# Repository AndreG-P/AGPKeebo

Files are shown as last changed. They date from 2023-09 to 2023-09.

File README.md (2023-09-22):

# AGPKeebo

The AGPKeebo is a 78 keys keyboard with a couple of unique features:

* General 65% layout with one extra key (language switch) on Row 5 (right-ALT and right-CTRL are U1)
* F1 - F10 keys in two separated columns
* 2x customizable knobs with push button function
* Each key contains two independent LEDs (1 north-facing and 1 south-facing LED)
* Additional independent LEDs for underglow
* 1x USB 2.0 Type C output for additional peripherals
* 1x SD Card reader

The main purpose of the two independent north- and south-facing LEDs was to allow highlighting certain keys for different language settings (e.g. highlight German "umlaute" such as ü or ö as side prints on the keys). However, this feature would require novel keycaps which do not exist yet. Making such keycaps are beyond the limitations of this project for now.

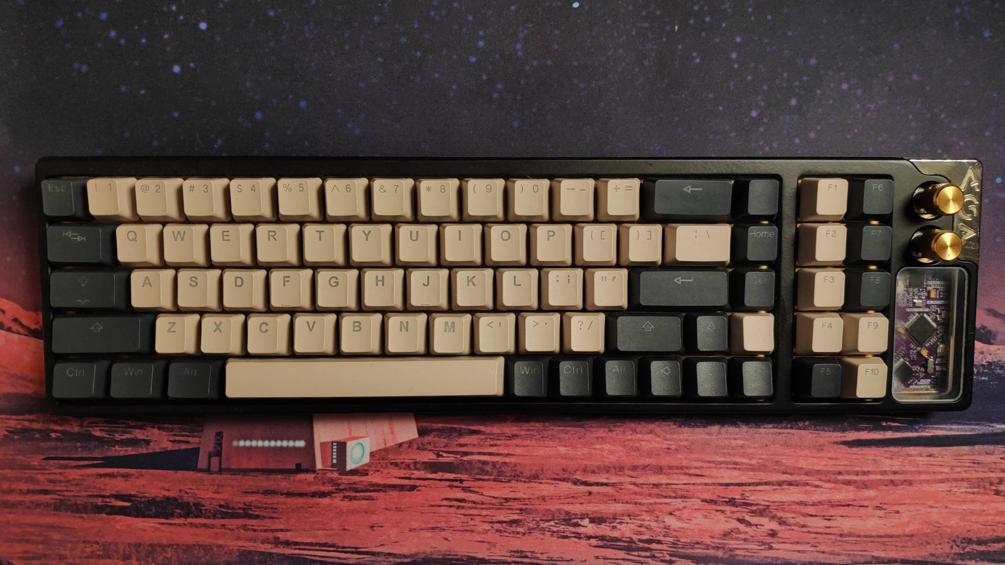
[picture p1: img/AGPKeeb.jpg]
Image of AGPKeeb


## Source Code

The [test](test) folder contains an STM32CubeIDE project to test the board and for training purposes. It will control all LEDs and keys so one can check if all connections work properly. The usb hub does not need further setup procedures and should work right out the box. 

### Technicalities

The board uses:

* STM32F411RET7 as the main MCU to control the keyboard logic
* USB2642 as the USB 2.0 HUB with integrated SD reader
* MAX14636CVB as USB Charge Detector to allow the board to draw up to 1.5A for all the LEDs
* 2x IS31FL3741 LED registers to control all LEDs
* 2x EEPROMS (one for USB hub and one for STM32F411) which are optional at this point

## PCB & Schematics

The PCB and the schematics were created using KiCad 6 and are available in the `pcb` folder. The `img` folder contains images for the key matrix layout.

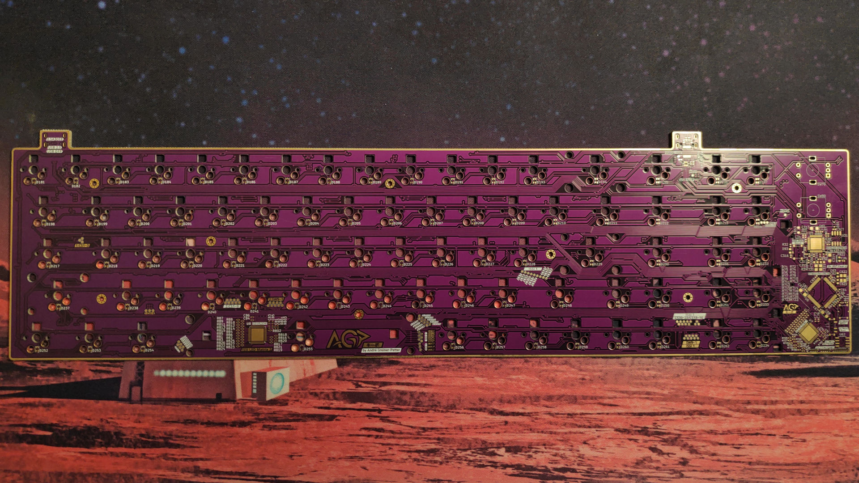
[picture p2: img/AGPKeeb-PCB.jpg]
Image of AGPKeeb's PCB


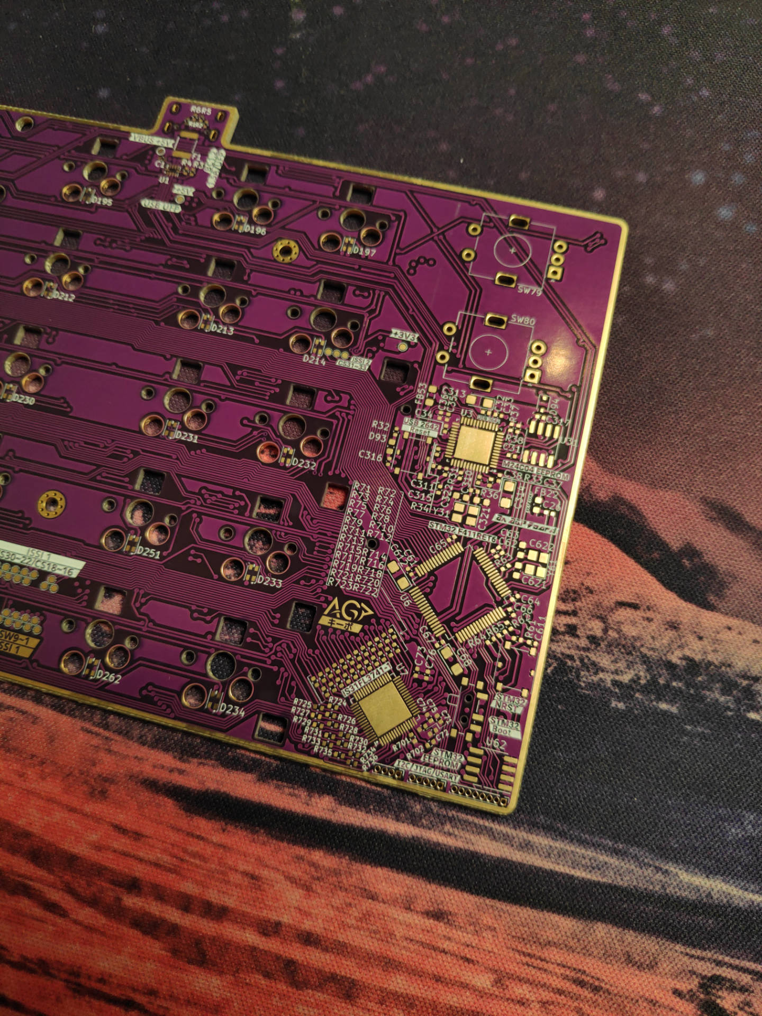
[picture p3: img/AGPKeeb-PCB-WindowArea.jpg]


### Case

Since the case is a non-standard layout, the `case` folder contains 3D step models to CNC or 3D print the case. The case design is a gasket mount style, of three layers + the plate sandwiched together. From top to bottom we have:
1. Top Layer
2. Plate
3. Middle acrylic layer for the underglow
4. Bottom Layer

Additionally, the case contains a weight (attached to the bottom layer), an artisan plate with magnet (R: 3mm, D: 1mm) holders, and an acrlic shield to cover the naked PCB for aesthetics. Besides step files it also contains a Fusion 360 archive file.

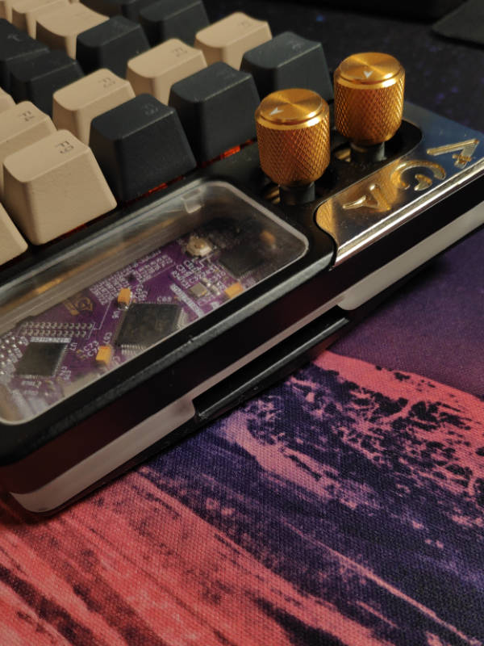
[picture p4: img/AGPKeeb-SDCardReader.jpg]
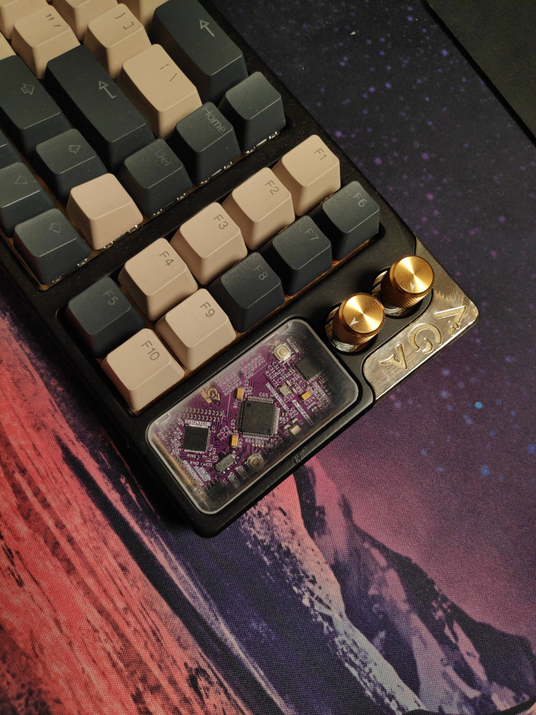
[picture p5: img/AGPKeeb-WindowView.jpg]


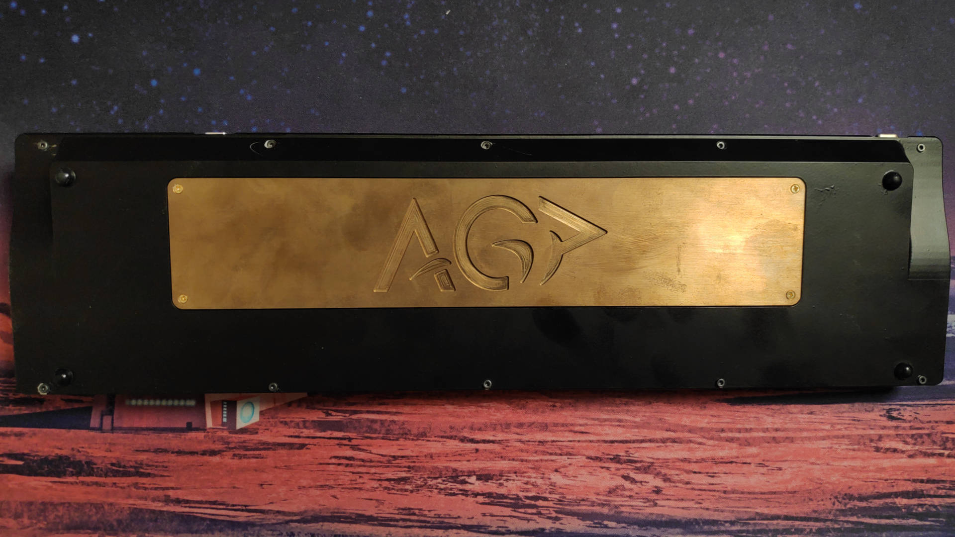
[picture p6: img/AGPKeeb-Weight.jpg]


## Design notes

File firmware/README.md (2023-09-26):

# AGPKeebo Firmware

The firmware of AGPKeebo is written with QMK and VIA. 

## Setup with VIA

In this folder you find the `via.json` which is necessary for VIA to detect AGPKeebo. In VIA (v3), switch to the design tab and load the JSON as the draft definition file. V2 should be disabled. Now the keyboard definition `AGP Keebo` should appear under `Shown Keyboard Definition` and you can use VIA to configure the keymaps.

## Initial Firmware Flash

If there is no QMK firmware on the board already, you must use STM32 flashing techniques. You can use the USB bootloader option by manually switch `STM32 boot` on the board (far right corner on the upper side of the board) and press `STM32 NRST` to restart. Now you can use STM32CubeIDE to flash firmware. Alternatively, use STM32CubeProgrammer with an ST-LINK debugger and connect it to the JTAG or USART connector on the board.

## Update Firmware

AGPKeeb is configured with magicboot option enabled. Hence, you only need to keep pressing `ESC` and plugin the keyboard. This starts the bootloader. From here on, you can use [QMK Toolbox](https://github.com/qmk/qmk_toolbox).

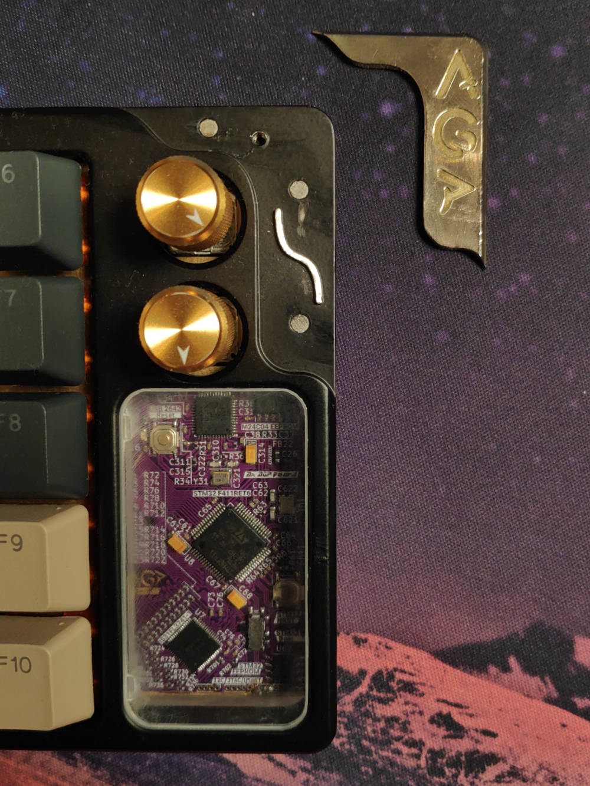
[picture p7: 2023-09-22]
img/AGPKeeb-Artisan.jpg

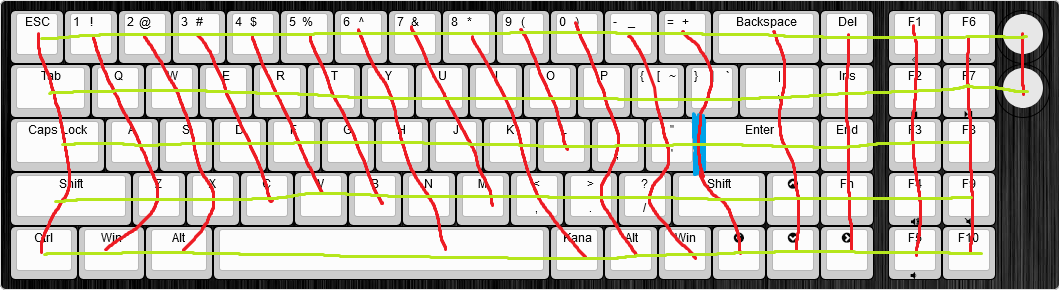
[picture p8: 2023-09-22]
img/AGPKeeb-KeyMatrix.png

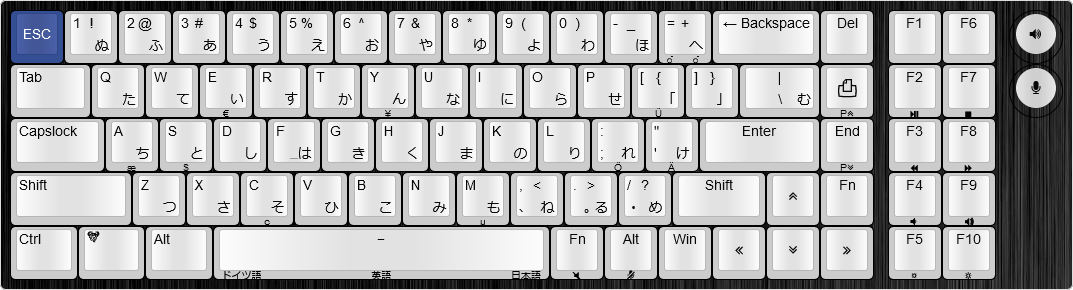
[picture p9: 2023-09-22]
img/AGPKeeb-Layout.png

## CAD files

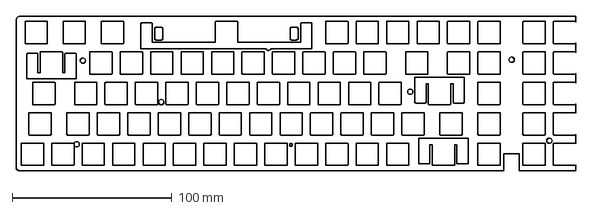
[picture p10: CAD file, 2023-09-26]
case/PCBFoamDXF.dxf
350.1 x 96.4 mm

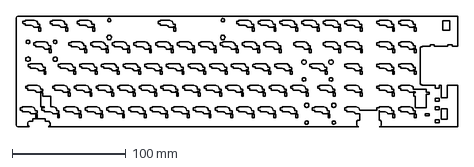
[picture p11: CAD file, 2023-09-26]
case/CaseFoamDXF.dxf
389.0 x 97.4 mm

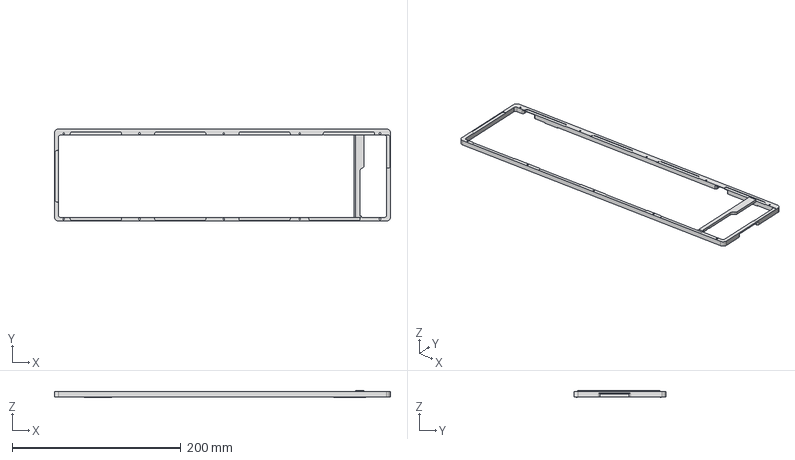
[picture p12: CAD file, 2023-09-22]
case/AGP-Keebo-Case-Middle.step
398.5 x 109.4 x 8.15 mm

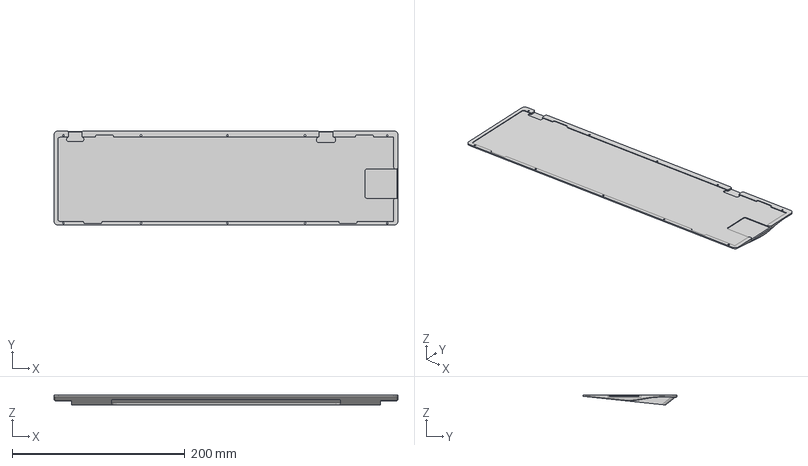
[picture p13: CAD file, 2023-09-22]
case/AGP-Keebo-Case-Bottom.step
398.5 x 109.4 x 11.6 mm

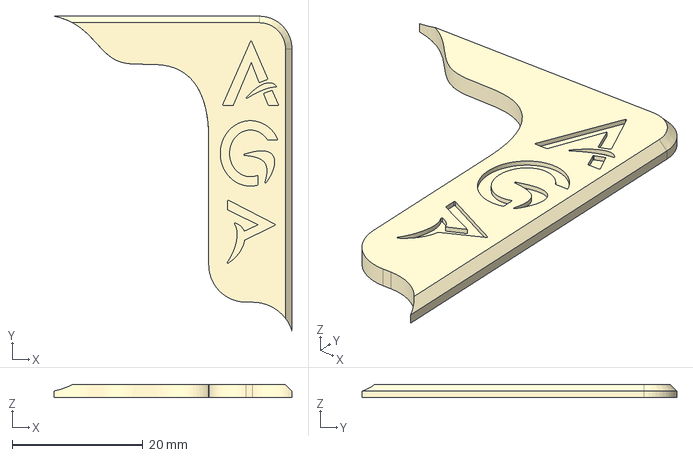
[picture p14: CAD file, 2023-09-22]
case/AGP-Keebo-Case-Artisan-Top.step
36.4 x 48.1 x 2.00 mm

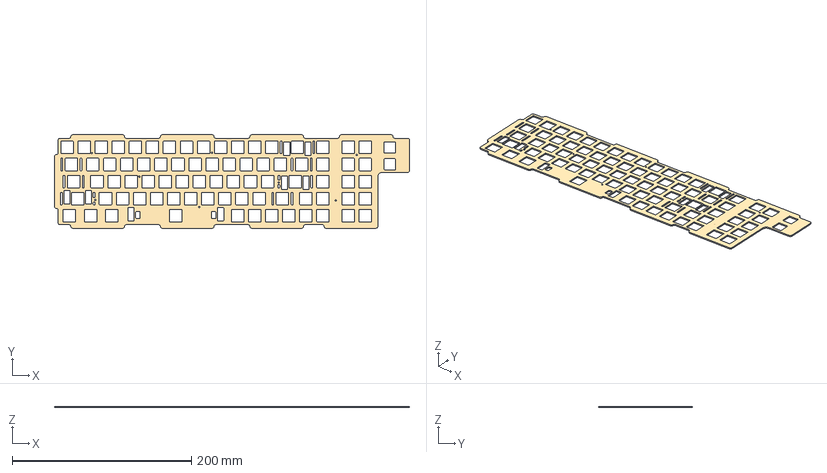
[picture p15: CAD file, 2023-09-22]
case/AGP-Keebo-Case-Plate-NoCounterSunk.step
396.5 x 104.4 x 1.50 mm

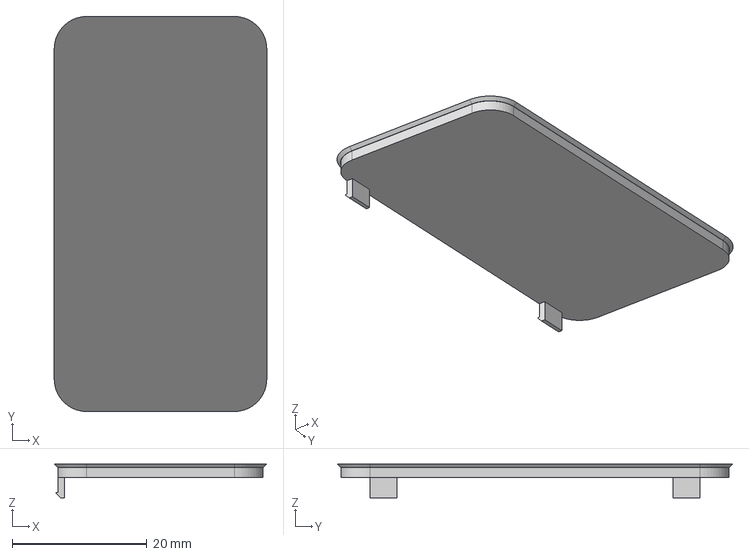
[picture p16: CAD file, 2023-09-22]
case/AGP-Keebo-Case-ClearCover.step
31.5 x 58.5 x 5.00 mm

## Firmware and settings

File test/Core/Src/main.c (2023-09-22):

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
/* Includes ------------------------------------------------------------------*/
#include "main.h"
#include "i2c.h"
#include "usart.h"
#include "usb_device.h"
#include "gpio.h"

/* USER CODE BEGIN Includes */
#include "is31fl3741.h"
#include "usbd_cdc_if.h"
#include "string.h"

/* USER CODE END Includes */


/* USER CODE BEGIN PV */
#define BYTE_TO_BINARY_PATTERN "%c%c%c%c%c%c%c%c"
#define BYTE_TO_BINARY(byte)  \
  ((byte) & 0x80 ? '1' : '0'), \
  ((byte) & 0x40 ? '1' : '0'), \
  ((byte) & 0x20 ? '1' : '0'), \
  ((byte) & 0x10 ? '1' : '0'), \
  ((byte) & 0x08 ? '1' : '0'), \
  ((byte) & 0x04 ? '1' : '0'), \
  ((byte) & 0x02 ? '1' : '0'), \
  ((byte) & 0x01 ? '1' : '0')

const uint8_t PWM_Gamma64Length = 64;
const uint8_t PWM_Gamma64[64] =
{
    0x00,0x01,0x02,0x03,0x04,0x05,0x06,0x07,
    0x08,0x09,0x0b,0x0d,0x0f,0x11,0x13,0x16,
    0x1a,0x1c,0x1d,0x1f,0x22,0x25,0x28,0x2e,
    0x34,0x38,0x3c,0x40,0x44,0x48,0x4b,0x4f,
    0x55,0x5a,0x5f,0x64,0x69,0x6d,0x72,0x77,
    0x7d,0x80,0x88,0x8d,0x94,0x9a,0xa0,0xa7,
    0xac,0xb0,0xb9,0xbf,0xc6,0xcb,0xcf,0xd6,
    0xe1,0xe9,0xed,0xf1,0xf6,0xfa,0xfe,0xff
};

const uint16_t ISSI1_LED_REGLength = IS31FL3741_FULL_SIZE;
uint8_t ISSI1_LED_REG[IS31FL3741_FULL_SIZE] = { 0 };

const uint16_t ISSI2_LED_REGLength = IS31FL3741_FULL_SIZE;
uint8_t ISSI2_LED_REG[IS31FL3741_FULL_SIZE] = { 0 };

uint8_t ISSI_DEFAULT_PWM = 0x03;
uint8_t ISSI_DEFAULT_SCALE = 0xA0;

IS31FL3741_LED led;
IS31FL3741_ADDR d1_addr;

int8_t rot1 = 0;
int8_t rot2 = 0;

int8_t active_row = 0;
const uint8_t NUM_OF_ROWS = 5;
uint16_t ROW_PINS[5] = {
    ROW1_Pin,
    ROW2_Pin,
    ROW3_Pin,
    ROW4_Pin,
    ROW5_Pin
};

GPIO_TypeDef *ROW_PORTS[5] = {
    ROW1_GPIO_Port,
    ROW2_GPIO_Port,
    ROW3_GPIO_Port,
    ROW4_GPIO_Port,
    ROW5_GPIO_Port
};

const uint8_t NUM_OF_COLS = 18;
uint16_t COL_PINS[18] = {
    COL1_Pin,
    COL2_Pin,
    COL3_Pin,
    COL4_Pin,
    COL5_Pin,
    COL6_Pin,
    COL7_Pin,
    COL8_Pin,
    COL9_Pin,
    COL10_Pin,
    COL11_Pin,
    COL12_Pin,
    COL13_Pin,
    COL14_Pin,
    COL15_Pin,
    COL16_Pin,
    COL17_Pin,
    COL18_Pin
};

GPIO_TypeDef *COL_PORTS[18] = {
    COL1_GPIO_Port,
    COL2_GPIO_Port,
    COL3_GPIO_Port,
    COL4_GPIO_Port,
    COL5_GPIO_Port,
    COL6_GPIO_Port,
    COL7_GPIO_Port,
    COL8_GPIO_Port,
    COL9_GPIO_Port,
    COL10_GPIO_Port,
    COL11_GPIO_Port,
    COL12_GPIO_Port,
    COL13_GPIO_Port,
    COL14_GPIO_Port,
    COL15_GPIO_Port,
    COL16_GPIO_Port,
    COL17_GPIO_Port,
    COL18_GPIO_Port
};

char keys[5][18] = {
        "E1234567890-=BDFFR",
        "Tqwertyuiop[]BIFFR",
        "Casdfghjkl;'EEFF",
        "Szxcvbnm,./SAFFF",
        "CWASKAWLDRFF"
};


// represents the entire matrix, each row is a single 32bit int each bit represents one col
uint8_t active_keys[5][18] = { 0 };

/* USER CODE END PV */

void SystemClock_Config(void);
/* USER CODE BEGIN PFP */
uint8_t One_By_One_LED_Mode(uint8_t address, char *msgBuffer);

void Scale_ISSI1_LEDs( uint8_t *reg );
void Scale_ISSI2_LEDs( uint8_t *reg );
/* USER CODE END PFP */

/* USER CODE BEGIN 0 */
void HAL_GPIO_EXTI_Callback(uint16_t GPIO_Pin) {
    // double detents per pulse so we need to keep track of raising AND falling edges
    if ( GPIO_Pin == ROT1_A_Pin ) {
        GPIO_PinState A_State = HAL_GPIO_ReadPin(ROT1_A_GPIO_Port, ROT1_A_Pin);
        GPIO_PinState B_State = HAL_GPIO_ReadPin(ROT1_B_GPIO_Port, ROT1_B_Pin);

        if ( A_State == B_State ) {
            rot1--;
        } else {
            rot1++;
        }

        if ( rot1 < 0 ) rot1 = 0;
        else if ( rot1 > 64 ) rot1 = 64;
    } else if ( GPIO_Pin == ROT2_A_Pin ) {
        GPIO_PinState A_State = HAL_GPIO_ReadPin(ROT2_A_GPIO_Port, ROT2_A_Pin);
        GPIO_PinState B_State = HAL_GPIO_ReadPin(ROT2_B_GPIO_Port, ROT2_B_Pin);

        if ( A_State == B_State ) {
            rot2--;
        } else {
            rot2++;
        }

        if ( rot2 < 0 ) rot2 = 0;
        else if ( rot2 > 64 ) rot2 = 64;
    }
}

void Scale_ISSI1_LEDs( uint8_t *reg ){
    uint8_t fullOnRange = (uint8_t) (IS31FL3741_REG_PG0_SIZE + 0x60);
    for ( uint8_t i = 0; i < fullOnRange; i++ ){
        reg[i] = ISSI_DEFAULT_SCALE;
    }

    // except CS25-27, SW2
    // which is 1E offset (SW2) + 24 (0x18)
    uint8_t offset = 0x1E + 0x18;
    reg[ offset ]       = 0x00;
    reg[ offset + 1 ]   = 0x00;
    reg[ offset + 2 ]   = 0x00;

    // add underglow
    uint8_t upperOffset = fullOnRange;
    uint8_t swSteps = 0x09;
    for ( uint8_t i = upperOffset+3; i+2 < IS31FL3741_FULL_SIZE; i += swSteps ) {
        reg[i]   = ISSI_DEFAULT_SCALE;
        reg[i+1] = ISSI_DEFAULT_SCALE;
        reg[i+2] = ISSI_DEFAULT_SCALE;
    }

    // activate window
    // CS31-33 SW3,6,7,8
    // SW3 + 18, SW6 + 0x2D
    reg[ fullOnRange+18 ]    = ISSI_DEFAULT_SCALE;
    reg[ fullOnRange+18+1 ]  = ISSI_DEFAULT_SCALE;
    reg[ fullOnRange+18+2 ]  = ISSI_DEFAULT_SCALE;

    for ( uint8_t i = upperOffset + 0x2D; i + 2 < fullOnRange + 0x48; i += swSteps ) {
        reg[i]   = ISSI_DEFAULT_SCALE;
        reg[i+1] = ISSI_DEFAULT_SCALE;
        reg[i+2] = ISSI_DEFAULT_SCALE;
    }
}

void Scale_ISSI2_LEDs( uint8_t *reg ){
    for ( uint8_t i = 0; i <= 0xB4 + 0x3D; i += 0x1E ) {
        for ( uint8_t j = 0; j < 21; j++ ) {
            reg[ i+j ] = ISSI_DEFAULT_SCALE;
        }
    }

    // except CS19-21, SW2
    // which is 1E offset (SW2) + 18 (0x12)
    reg[ 0x1E + 0x12 ]      = 0x00;
    reg[ 0x1E + 0x12 + 1 ]  = 0x00;
    reg[ 0x1E + 0x12 + 2 ]  = 0x00;

    // CS34-39 SW1-9
    // add underglow
    uint8_t upperOffset = (uint8_t) (IS31FL3741_REG_PG0_SIZE + 0x60);
    uint8_t swSteps = 0x09;
    for ( uint8_t i = upperOffset + 3; i+5 <= IS31FL3741_FULL_SIZE; i += swSteps ) {
        for ( uint8_t j = 0; j < 6; j++ ) {
            reg[i]   = ISSI_DEFAULT_SCALE;
        }
    }
}

uint8_t One_By_One_LED_Mode(uint8_t address, char *msgBuffer) {
    if ( IS31FL3741_SetLED( &led, address ) != HAL_OK ) {
        sprintf(msgBuffer, "Unable to light up LED 0x%02X on page 0x%02X.\r\n", d1_addr.addr, d1_addr.page);
        CDC_Transmit_FS((uint8_t *) msgBuffer, strlen(msgBuffer));
    }

    HAL_Delay(500);

    led.value[0] = 0x00;
    led.value[1] = 0x00;
    led.value[2] = 0x00;

    if ( IS31FL3741_SetLED( &led, address ) != HAL_OK ) {
        sprintf(msgBuffer, "Unable to turn off LED 0x%02X on page 0x%02X.\r\n", d1_addr.addr, d1_addr.page);
        CDC_Transmit_FS((uint8_t *) msgBuffer, strlen(msgBuffer));
    }

    d1_addr.addr = d1_addr.addr + 3;
    if ( d1_addr.page == 0 && d1_addr.addr >= IS31FL3741_REG_PG0_SIZE ) {
        d1_addr.page = 0x01;
        d1_addr.addr = 0x00;
    } else if ( d1_addr.page == 1 && d1_addr.addr >= IS31FL3741_REG_PG1_SIZE ) {
        d1_addr.page = 0x00;
        d1_addr.addr = 0x00;
        if ( address == IS31FL3741_I2C_ADDR_1 )
            address = IS31FL3741_I2C_ADDR_2;
        else
            address = IS31FL3741_I2C_ADDR_1;
    }

    led.value[0] = 0xFF;
    led.value[1] = 0xFF;
    led.value[2] = 0xFF;

    if ( IS31FL3741_SetLED( &led, address ) != HAL_OK ) {
        sprintf(msgBuffer, "Unable to light up LED 0x%02X on page 0x%02X.\r\n", d1_addr.addr, d1_addr.page);
        CDC_Transmit_FS((uint8_t *) msgBuffer, strlen(msgBuffer));
    }

    return address;
}

/* USER CODE END 0 */

/**
  * @brief  The application entry point.
  * @retval int
  */
int main(void)
{
  /* MCU Configuration--------------------------------------------------------*/

  /* Reset of all peripherals, Initializes the Flash interface and the Systick. */
  HAL_Init();

  /* Configure the system clock */
  SystemClock_Config();

  /* Initialize all configured peripherals */
  MX_GPIO_Init();
  MX_I2C1_Init();
  MX_USART1_Init();
  MX_USB_DEVICE_Init();
  /* USER CODE BEGIN 2 */

  led.i2cHandle = &hi2c1;
  led.setting = PWM;
  led.addr = &d1_addr;
  led.value[0] = 0xFF;
  led.value[1] = 0xFF;
  led.value[2] = 0xFF;

  d1_addr.page = 0x00;
  d1_addr.addr = 0x00;

    HAL_Delay(5000);
    char msgBuffer[256];
    uint8_t id[3];

    // testing ISSI-1 by reading its I2C address from memory
    if( IS31FL3741_ReadID( &hi2c1, IS31FL3741_I2C_ADDR_1, id ) != HAL_OK ) {
        sprintf(msgBuffer, "Error during transmitting I2C data to ISSI-1\r\n");
    } else if ( id[0] != IS31FL3741_I2C_ADDR_1 ) {
        sprintf(msgBuffer, "ISSI-1 responded with wrong ID: 0x%02X; expected: 0x%02X\r\n", id[0], IS31FL3741_I2C_ADDR_1);
    } else {
        sprintf(msgBuffer, "ISSI-1 address check successful\r\n");
    }

    CDC_Transmit_FS((uint8_t *) msgBuffer, strlen(msgBuffer));
    HAL_Delay(500);

    // testing ISSI-2 by reading its I2C address from memory
    if( IS31FL3741_ReadID( &hi2c1, IS31FL3741_I2C_ADDR_2, id ) != HAL_OK ) {
        sprintf(msgBuffer, "Error during transmitting I2C data to ISSI-2\r\n");
    } else if ( id[0] != IS31FL3741_I2C_ADDR_2 ) {
        sprintf(msgBuffer, "ISSI-2 responded with wrong ID: 0x%02X; expected: 0x%02X\r\n", id[0], IS31FL3741_I2C_ADDR_2);
    } else {
        sprintf(msgBuffer, "ISSI-2 address check successful\r\n");
    }

    CDC_Transmit_FS((uint8_t *) msgBuffer, strlen(msgBuffer));
    HAL_Delay(500);

    sprintf(msgBuffer, "Init LED registers\r\n");
    CDC_Transmit_FS((uint8_t *) msgBuffer, strlen(msgBuffer));

//    Scale_ISSI1_LEDs( ISSI1_LED_REG );

    for ( uint16_t i = 0; i < IS31FL3741_FULL_SIZE; i++ ){
        ISSI1_LED_REG[i] = 0xFF;
    }

    for ( uint16_t i = 0; i < IS31FL3741_FULL_SIZE; i++ ){
        ISSI2_LED_REG[i] = 0xFF;
    }

//    Scale_ISSI2_LEDs( ISSI2_LED_REG );
    HAL_Delay(500);

    sprintf(msgBuffer, "Finish setting scale values.\r\n");
    CDC_Transmit_FS((uint8_t *) msgBuffer, strlen(msgBuffer));

    HAL_Delay(500);
    sprintf(msgBuffer, "Init ISSI 1.\r\n");
    CDC_Transmit_FS((uint8_t *) msgBuffer, strlen(msgBuffer));

    IS31FL3741_Init( &hi2c1, IS31FL3741_I2C_ADDR_1, ISSI1_LED_REG, ISSI1_LED_REGLength, &ISSI_DEFAULT_PWM );

    HAL_Delay(500);
    sprintf(msgBuffer, "Init ISSI 2.\r\n");
    CDC_Transmit_FS((uint8_t *) msgBuffer, strlen(msgBuffer));

    IS31FL3741_Init( &hi2c1, IS31FL3741_I2C_ADDR_2, ISSI2_LED_REG, ISSI2_LED_REGLength, &ISSI_DEFAULT_PWM );
//
//    HAL_Delay(2000);
//    sprintf(msgBuffer, "Init ISSI 2 (init).\r\n");
//    CDC_Transmit_FS((uint8_t *) msgBuffer, strlen(msgBuffer));
//    IS31FL3741_Init( &hi2c1, IS31FL3741_I2C_ADDR_2, ISSI2_LED_REG, ISSI2_LED_REGLength, &ISSI_DEFAULT_PWM );
//
//    sprintf(msgBuffer, "All setup done. Try lighting up a single LED. Confirm values are 0.\r\n");
//    CDC_Transmit_FS((uint8_t *) msgBuffer, strlen(msgBuffer));



    // ==================================== CHECK CAPSLOCK VALUES =================================
//    d1_addr.page = 0x00;
//    d1_addr.addr = 0x78; // CS1, SW5 (capslock blue)
//
//    IS31FL3741_Unlock( &hi2c1, IS31FL3741_I2C_ADDR_1 );
//    IS31FL3741_OpenPage(&hi2c1, d1_addr.page, IS31FL3741_I2C_ADDR_1 );
//    if ( HAL_I2C_Mem_Read(&hi2c1, IS31FL3741_I2C_ADDR_1, d1_addr.addr, I2C_MEMADD_SIZE_8BIT, id, I2C_MEMADD_SIZE_8BIT*3, IS31FL3741_I2C_TIMEOUT) != HAL_OK ){
//        sprintf(msgBuffer, "Unable to read PWM LED CapsLock values.\r\n");
//        CDC_Transmit_FS((uint8_t *) msgBuffer, strlen(msgBuffer));
//    } else {
//        sprintf(msgBuffer, "CapsLock LED PWM is set: 0x%02X, 0x%02X, 0x%02X\r\n", id[0], id[1], id[2]);
//        CDC_Transmit_FS((uint8_t *) msgBuffer, strlen(msgBuffer));
//    }
//
//    d1_addr.page = 0x02;
//    IS31FL3741_Unlock( &hi2c1, IS31FL3741_I2C_ADDR_1 );
//    IS31FL3741_OpenPage(&hi2c1, d1_addr.page, IS31FL3741_I2C_ADDR_1 );
//    if ( HAL_I2C_Mem_Read(&hi2c1, IS31FL3741_I2C_ADDR_1, d1_addr.addr, I2C_MEMADD_SIZE_8BIT, id, I2C_MEMADD_SIZE_8BIT*3, IS31FL3741_I2C_TIMEOUT) != HAL_OK ){
//        sprintf(msgBuffer, "Unable to read SCALE LED CapsLock values.\r\n");
//        CDC_Transmit_FS((uint8_t *) msgBuffer, strlen(msgBuffer));
//    } else {
//        sprintf(msgBuffer, "CapsLock LED SCALE is set: 0x%02X, 0x%02X, 0x%02X\r\n", id[0], id[1], id[2]);
//        CDC_Transmit_FS((uint8_t *) msgBuffer, strlen(msgBuffer));
//    }
//
//    HAL_Delay(500);
//    sprintf(msgBuffer, "Expected Scale Values: 0x%02X, 0x%02X, 0x%02X\r\n", ISSI1_LED_REG[d1_addr.addr], ISSI1_LED_REG[d1_addr.addr+1], ISSI1_LED_REG[d1_addr.addr+2]);
//    CDC_Transmit_FS((uint8_t *) msgBuffer, strlen(msgBuffer));
    // ==================================== CHECK CAPSLOCK VALUES =================================

//
//    IS31FL3741_OpenPage(&hi2c1, 0x02, IS31FL3741_I2C_ADDR_1 );
//    if ( HAL_I2C_Mem_Read(&hi2c1, IS31FL3741_I2C_ADDR_1, 0x02, I2C_MEMADD_SIZE_8BIT, &id[0], I2C_MEMADD_SIZE_8BIT, IS31FL3741_I2C_TIMEOUT) != HAL_OK ){
//        sprintf(msgBuffer, "Unable to read SCALE LED 0 values.\r\n");
//        CDC_Transmit_FS((uint8_t *) msgBuffer, strlen(msgBuffer));
//    } else {
//        sprintf(msgBuffer, "LED 1 SCALE is set: 0x%02X\r\n", id[0]);
//        CDC_Transmit_FS((uint8_t *) msgBuffer, strlen(msgBuffer));
//    }
//
//    sprintf(msgBuffer, "Start lighting up LEDs one by one (complete white)\r\n");
//    CDC_Transmit_FS((uint8_t *) msgBuffer, strlen(msgBuffer));
//


  /* USER CODE END 2 */

  /* Infinite loop */
  /* USER CODE BEGIN WHILE */

    char buffer[NUM_OF_ROWS][NUM_OF_COLS+1];

    for ( uint8_t i = 0; i < NUM_OF_ROWS; i++ ){
        buffer[i][NUM_OF_COLS] = '\0';
    }

    while (1)
    {
        // ================================ ACTIVATE ROWS =============================
        // pull row high

        for ( uint8_t col = 0; col < NUM_OF_COLS; col++ ) {
            HAL_GPIO_WritePin(COL_PORTS[col], COL_PINS[col], GPIO_PIN_SET);

            for ( uint8_t row = 0; row < NUM_OF_ROWS; row++ ) {
                active_keys[row][col] = HAL_GPIO_ReadPin(ROW_PORTS[row], ROW_PINS[row]);
                if ( active_keys[row][col] )
                    buffer[row][col] = keys[row][col];
                else buffer[row][col] = ' ';
            }

            HAL_GPIO_WritePin(COL_PORTS[col], COL_PINS[col], GPIO_PIN_RESET);
            HAL_Delay(10);
        }

//        for ( uint8_t row = 0; row < NUM_OF_ROWS; row++ ) {
//            snprintf(intBuffer, 20, "%d", (int) active_keys[row]);
//        }

        sprintf(msgBuffer, "Keyboard Matrix:\r\n%19s | %d\r\n%19s | %d\r\n%19s\r\n%19s\r\n%19s\r\n\r\n",
                buffer[0], rot1,
                buffer[1], rot2,
                buffer[2],
                buffer[3],
                buffer[4]);
        CDC_Transmit_FS((uint8_t *) msgBuffer, strlen(msgBuffer));

//        if ( active_row == 0 ) {
//            sprintf(msgBuffer, "Keyboard Matrix:\r\n"BYTE_TO_BINARY_PATTERN" "BYTE_TO_BINARY_PATTERN" "BYTE_TO_BINARY_PATTERN" "BYTE_TO_BINARY_PATTERN" | %02d\r\n"BYTE_TO_BINARY_PATTERN" "BYTE_TO_BINARY_PATTERN" "BYTE_TO_BINARY_PATTERN" "BYTE_TO_BINARY_PATTERN" | %02d\r\n"BYTE_TO_BINARY_PATTERN" "BYTE_TO_BINARY_PATTERN" "BYTE_TO_BINARY_PATTERN" "BYTE_TO_BINARY_PATTERN"\r\n"BYTE_TO_BINARY_PATTERN" "BYTE_TO_BINARY_PATTERN" "BYTE_TO_BINARY_PATTERN" "BYTE_TO_BINARY_PATTERN"\r\n"BYTE_TO_BINARY_PATTERN" "BYTE_TO_BINARY_PATTERN" "BYTE_TO_BINARY_PATTERN" "BYTE_TO_BINARY_PATTERN"\r\n\r\n",
//                    BYTE_TO_BINARY(active_cols[0]>>24), BYTE_TO_BINARY(active_cols[0]>>16), BYTE_TO_BINARY(active_cols[0]>>8), BYTE_TO_BINARY(active_cols[0]), rot1,
//                    BYTE_TO_BINARY(active_cols[1]>>24), BYTE_TO_BINARY(active_cols[1]>>16), BYTE_TO_BINARY(active_cols[1]>>8), BYTE_TO_BINARY(active_cols[1]), rot2,
//                    BYTE_TO_BINARY(active_cols[2]>>24), BYTE_TO_BINARY(active_cols[2]>>16), BYTE_TO_BINARY(active_cols[2]>>8), BYTE_TO_BINARY(active_cols[2]),
//                    BYTE_TO_BINARY(active_cols[3]>>24), BYTE_TO_BINARY(active_cols[3]>>16), BYTE_TO_BINARY(active_cols[3]>>8), BYTE_TO_BINARY(active_cols[3]),
//                    BYTE_TO_BINARY(active_cols[4]>>24), BYTE_TO_BINARY(active_cols[4]>>16), BYTE_TO_BINARY(active_cols[4]>>8), BYTE_TO_BINARY(active_cols[4])
//                    );
//            CDC_Transmit_FS((uint8_t *) msgBuffer, strlen(msgBuffer));
//        }

//        address = One_By_One_LED_Mode(address, msgBuffer);
//
//        sprintf(msgBuffer, "Light LED 0x%02X on page 0x%02X (ISSI: 0x%02X).\r\n", d1_addr.addr, d1_addr.page, address);
//        CDC_Transmit_FS((uint8_t *) msgBuffer, strlen(msgBuffer));

//        sprintf(msgBuffer, "Idle.\r\n");
//        CDC_Transmit_FS((uint8_t *) msgBuffer, strlen(msgBuffer));

        // ================================== ENCODER HARDCODED =================================
//        if ( HAL_GPIO_ReadPin(ROT1_A_GPIO_Port, ROT1_A_Pin) == GPIO_PIN_RESET ) {
//            // means A was pulled low
//            if ( HAL_GPIO_ReadPin(ROT1_B_GPIO_Port, ROT1_B_Pin) == GPIO_PIN_RESET ) {
//                // B is already pulled low, so B was pulled before A, hence CCW
//                while ( HAL_GPIO_ReadPin(ROT1_B_GPIO_Port, ROT1_B_Pin) == GPIO_PIN_RESET ) {}
//                counter--;
//                while ( HAL_GPIO_ReadPin(ROT1_A_GPIO_Port, ROT1_A_Pin) == GPIO_PIN_RESET ) {}
//                HAL_Delay(10);
//            } else {
//                // means A is low but B is still low. Hence, CW, wait for B to be pulled LOW too
//                while ( HAL_GPIO_ReadPin(ROT1_B_GPIO_Port, ROT1_B_Pin) == GPIO_PIN_SET ) {}
//                // now we are essentially in the top case and wait for A to be pulled high again
//
//                counter++;
//                while ( HAL_GPIO_ReadPin(ROT1_A_GPIO_Port, ROT1_A_Pin) == GPIO_PIN_RESET ) {}
//                // and lastly B being back to normal too
//                while ( HAL_GPIO_ReadPin(ROT1_B_GPIO_Port, ROT1_B_Pin) == GPIO_PIN_RESET ) {}
//                HAL_Delay(10);
//            }
//
//
//
//            // some normalization so we dont get out of bounds
//            if ( counter < 0  ) counter = 0;
//            if ( counter > 64 ) counter = 64;
//
//        }


        // ===================== FIND ISSUE OF NOT WORKING I2C ================================
        for ( uint16_t i = 0; i < IS31FL3741_FULL_SIZE; i++ ){
            ISSI1_LED_REG[i] = PWM_Gamma64[rot1];
        }

        IS31FL3741_WriteAllLEDs( &hi2c1, IS31FL3741_I2C_ADDR_1, ISSI1_LED_REG );
        IS31FL3741_WriteAllLEDs( &hi2c1, IS31FL3741_I2C_ADDR_2, ISSI1_LED_REG );

//        sprintf(msgBuffer, "Counter %02d LEDs PWM to 0x%02X.\r\n", rot1, PWM_Gamma64[rot1]);
//        CDC_Transmit_FS((uint8_t *) msgBuffer, strlen(msgBuffer));

//        HAL_Delay(500);
    /* USER CODE END WHILE */

    /* USER CODE BEGIN 3 */
    }
  /* USER CODE END 3 */
}

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
/**
  * @brief  Period elapsed callback in non blocking mode
  * @note   This function is called  when TIM1 interrupt took place, inside
  * HAL_TIM_IRQHandler(). It makes a direct call to HAL_IncTick() to increment
  * a global variable "uwTick" used as application time base.
  * @param  htim : TIM handle
  * @retval None
  */
void HAL_TIM_PeriodElapsedCallback(TIM_HandleTypeDef *htim)
{
  if (htim->Instance == TIM1) {
    HAL_IncTick();
  }
}

/**
  * @brief  This function is executed in case of error occurrence.
  * @retval None
  */
void Error_Handler(void)
{
  /* USER CODE BEGIN Error_Handler_Debug */
  /* User can add his own implementation to report the HAL error return state */
  __disable_irq();
  while (1)
  {
  }
  /* USER CODE END Error_Handler_Debug */
}

#ifdef  USE_FULL_ASSERT
/**
  * @brief  Reports the name of the source file and the source line number
  *         where the assert_param error has occurred.
  * @param  file: pointer to the source file name
  * @param  line: assert_param error line source number
  * @retval None
  */
void assert_failed(uint8_t *file, uint32_t line)
{
  /* USER CODE BEGIN 6 */
  /* User can add his own implementation to report the file name and line number,
     ex: printf("Wrong parameters value: file %s on line %d\r\n", file, line) */
  /* USER CODE END 6 */
}
#endif /* USE_FULL_ASSERT */

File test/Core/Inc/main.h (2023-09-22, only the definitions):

#define ROT2_A_Pin GPIO_PIN_13
#define ROT2_A_GPIO_Port GPIOC
#define ROT2_A_EXTI_IRQn EXTI15_10_IRQn
#define ROT2_B_Pin GPIO_PIN_14
#define ROT2_B_GPIO_Port GPIOC
#define ROT1_A_Pin GPIO_PIN_1
#define ROT1_A_GPIO_Port GPIOC
#define ROT1_A_EXTI_IRQn EXTI1_IRQn
#define ROT1_B_Pin GPIO_PIN_2
#define ROT1_B_GPIO_Port GPIOC
#define HOST_CC1_Pin GPIO_PIN_0
#define HOST_CC1_GPIO_Port GPIOA
#define HOST_CC2_Pin GPIO_PIN_1
#define HOST_CC2_GPIO_Port GPIOA
#define CHG_DET_Pin GPIO_PIN_2
#define CHG_DET_GPIO_Port GPIOA
#define SW_USB_Pin GPIO_PIN_3
#define SW_USB_GPIO_Port GPIOA
#define COL18_Pin GPIO_PIN_4
#define COL18_GPIO_Port GPIOA
#define COL17_Pin GPIO_PIN_5
#define COL17_GPIO_Port GPIOA
#define COL16_Pin GPIO_PIN_6
#define COL16_GPIO_Port GPIOA
#define COL15_Pin GPIO_PIN_7
#define COL15_GPIO_Port GPIOA
#define COL14_Pin GPIO_PIN_4
#define COL14_GPIO_Port GPIOC
#define COL13_Pin GPIO_PIN_5
#define COL13_GPIO_Port GPIOC
#define COL12_Pin GPIO_PIN_0
#define COL12_GPIO_Port GPIOB
#define COL11_Pin GPIO_PIN_1
#define COL11_GPIO_Port GPIOB
#define COL10_Pin GPIO_PIN_2
#define COL10_GPIO_Port GPIOB
#define COL9_Pin GPIO_PIN_10
#define COL9_GPIO_Port GPIOB
#define COL8_Pin GPIO_PIN_12
#define COL8_GPIO_Port GPIOB
#define COL7_Pin GPIO_PIN_13
#define COL7_GPIO_Port GPIOB
#define COL6_Pin GPIO_PIN_14
#define COL6_GPIO_Port GPIOB
#define COL5_Pin GPIO_PIN_15
#define COL5_GPIO_Port GPIOB
#define COL4_Pin GPIO_PIN_6
#define COL4_GPIO_Port GPIOC
#define COL3_Pin GPIO_PIN_7
#define COL3_GPIO_Port GPIOC
#define COL2_Pin GPIO_PIN_8
#define COL2_GPIO_Port GPIOC
#define COL1_Pin GPIO_PIN_9
#define COL1_GPIO_Port GPIOC
#define ROW3_Pin GPIO_PIN_10
#define ROW3_GPIO_Port GPIOC
#define ROW4_Pin GPIO_PIN_11
#define ROW4_GPIO_Port GPIOC
#define ROW5_Pin GPIO_PIN_12
#define ROW5_GPIO_Port GPIOC
#define EEPROM_WP_Pin GPIO_PIN_5
#define EEPROM_WP_GPIO_Port GPIOB
#define ROW2_Pin GPIO_PIN_8
#define ROW2_GPIO_Port GPIOB
#define ROW1_Pin GPIO_PIN_9
#define ROW1_GPIO_Port GPIOB

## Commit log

2023-09-22 Adding KiCad ignore settings
2023-09-22 Adding KiCad 6 project files
    [AGPKeeb.kicad_sch, keyledmatrix.kicad_sch, led_matrix.kicad_sch]
2023-09-22 Adding 3D files for the case
    [AGP-Keebo-Case-Artisan-Top.step, AGP-Keebo-Case-Bottom.step, AGP-Keebo-Case-ClearCover.step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]
2023-09-26 Fix issue of misplaced silkscreen
2023-09-26 Add foam DXF designs
    [CaseFoamDXF.dxf, PCBFoamDXF.dxf]

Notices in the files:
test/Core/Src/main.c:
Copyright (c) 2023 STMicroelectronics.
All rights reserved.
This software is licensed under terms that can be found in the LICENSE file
